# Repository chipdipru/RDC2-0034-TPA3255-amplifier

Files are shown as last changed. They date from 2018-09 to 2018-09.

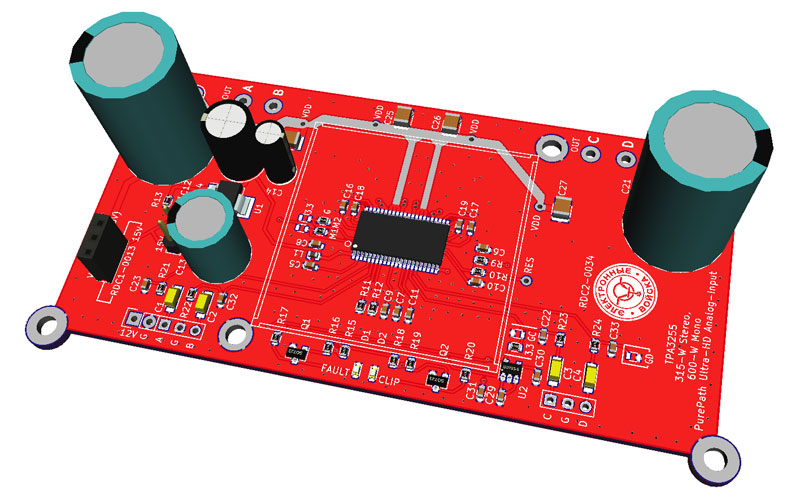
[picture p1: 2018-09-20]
RDC2-0034/pic/rdc2-0034.jpg

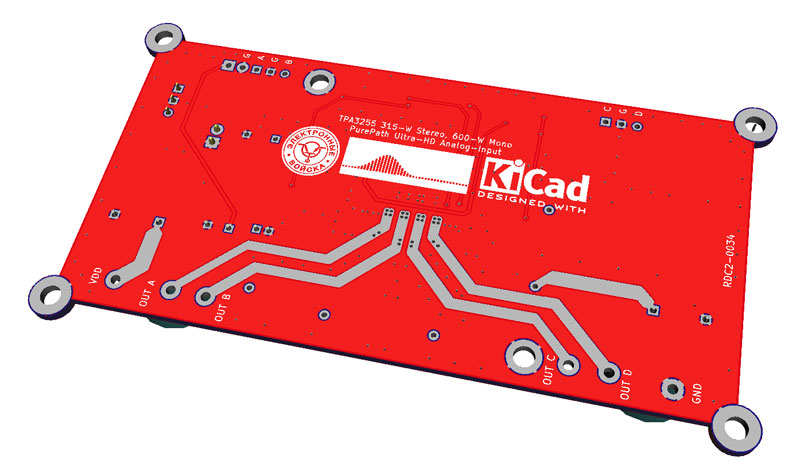
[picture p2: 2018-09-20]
RDC2-0034/pic/rdc2-0034_bot.jpg

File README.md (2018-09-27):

<p><a href="https://static.chipdip.ru/lib/893/DOC003893644.jpg" class="galery">RDC2-0034</a></p>

<p>Модуль RDC2-0034 представляет собой высокопроизводительный усилитель мощности класса D, который совмещает истинное качество звука премиум-класса с высоким КПД класса D.<br>Усилитель построен на микросхеме TPA3255. Это стереофонический аналоговый чип с цифровым усилителем Power Stage, предназначенный для работы с 4-омными громкоговорителями мощностью до 300 Вт на канал. Он имеет усовершенствованную интегрированную конструкцию обратной связи и исправление ошибок драйвера высокоскоростного шлюза (PurePath ™ Ultra-HD). Эта технология обеспечивает сверхнизкие искажения в звуковом диапазоне и превосходное качество звука.<br>RDC2-0034 сконфигурирован для работы с двумя каналами включенными по мостовой схеме (BTL).<br/>
 На аналоговый вход усилителя можно подавать как несимметричный так и симметричный (дифференциальный) сигнал.<br/>
 При необходимости два мостовых канала BTL можно включить параллельно, объединив их в один канал PBTL. При этом выходная мощность усилителя достигнет 600Вт.<br>Для обеспечения высококачественного высокоэффективного усиления звука требуется простой пассивный фильтр демодуляции цифрового сигнала. Модуль LCF.<br>Для питания схем управления и обработки сигнала усилителю требуется дополнительные источники питания – 12В и 3,3В. Модуль RDC1-0013 сформирует 15В из напряжения питания выходного каскада, а параметрические преобразователи на главной плате отдадут требуемые 12В и 3,3В.</p>
<h2>Технические характеристики</h2>
<p>Напряжение питания выходного каскада: 18-50 В<br>Количество каналов: 2 x BTL, 1 x PBTL<br>Сопротивление нагрузки: BTL 4-8 Ом<br>Сопротивление нагрузки: PBTL 2-3 Ом<br>Выходная мощность: BTL 318 Вт / 4 Ом 10% THD или 180 Вт / 8 Ом / 10% THD<br>Выходная мощность PBTL 607 Вт / 2 Ом / 10% THD<br>Выходная мощность: BTL 260 Вт / 4 Ом 1% THD или 150 Вт / 8 Ом / 1% THD<br>Выходная мощность: PBTL 480 Вт / 2 Ом / 1% THD<br>Коэффициент нелинейных искажений:0.006%<br>КПД с нагрузкой 4Ом: 90%</p>
<p>Схема основной платы усилителя.</p>
<p><a href="https://static.chipdip.ru/kits/9000491544/RDC2-0034_sch.png" class="galery">Схема</a></p>
<p>Подробную инструкцию по включению и конфигурации усилителя можно найти в разделе «Документы».</p>
<p>Это открытый проект! Лицензия, под которой он распространяется – <a href="https://creativecommons.org/licenses/by-sa/3.0/" class="link">Creative Commons - Attribution - Share Alike license</a>.</p>

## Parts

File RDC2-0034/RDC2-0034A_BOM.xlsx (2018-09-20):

RDC2-0034A
quantity | position | description | Manufacture
1 | IC1 | TPA3255DDV
1 | U1 | LM317AEMP SOT-223
1 | U2 | LP2985-33DBVR SOT-23-5
2 | Q1, Q2 | 2N7002
2 | D1, D2 | 0603 RED LED
4 | R1-R4 | DNP
2 | R5,R7 | DNP
2 | R6,R8 | R0 0603
1 | R9, R15, R18 | 47k, 0603 1%
3 | R10, R16, R19 | 100R, 0603 1%
1 | R11 | 22k, 0603 1%
1 | R12 | 30k, 0603 1%
1 | R13 | 4.7k, 0603 1%
1 | R14 | 560R, 0603 1%
2 | R17, R20 | 1k, 0603 1%
4 | C1-C4 | TECAP 10/10V A
4 | C5, C8, C10, C12 | 0.1u 0603
5 | C6, C22, C23, C32, C33 | 100p 0603
2 | C7, C9 | 1uF 0603
1 | C11 | 0,047 uF 0603 10%
4 | C16, C17, C18, C19 | 0,033 uF 0603 10% 50V
5 | C24, C25, C26, C27, C28 | 2,2 uF 1210 10% 100V
1 | C29 | 1 uF 0603 10%
1 | C30 | 0,01 uF 0603 10%
1 | C31 | 4,7 uF 0603 10%
1 | L1 | Inductor 10 μH, 0.08 A
2 | C20, C21 | 1000uF 63V D16 L25 P7.5
1 | C13 | 470uF 25V D10 L13 P5
1 | C14 | 10uF 35V D5 L11 P2
1 | C15 | 100uF 25 D8 L11.5 P3.5
1 | P3 | PBS-3
1 |  | PCB RDC2-0034

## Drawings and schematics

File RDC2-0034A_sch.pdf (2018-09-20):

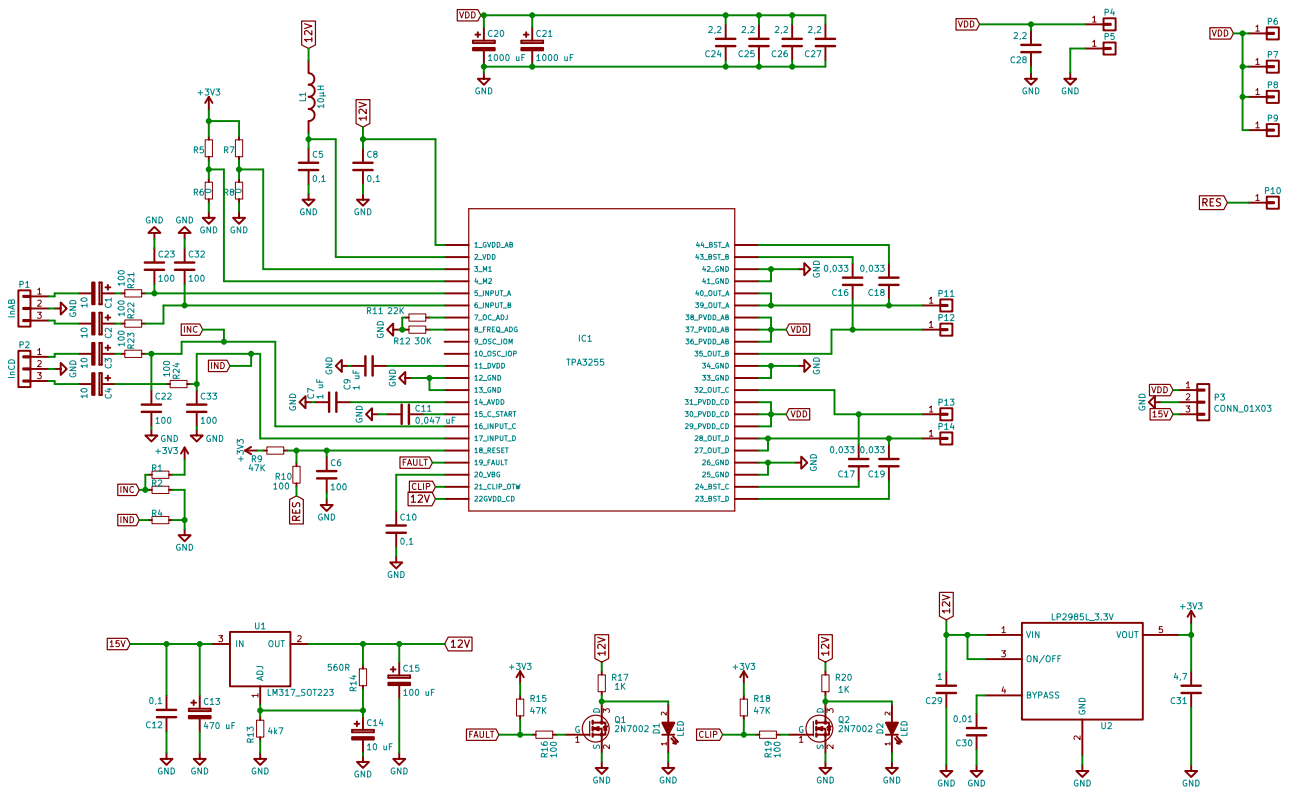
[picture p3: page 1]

2 ON/OFF 3 BYPASS 4 VOUT 5 U2

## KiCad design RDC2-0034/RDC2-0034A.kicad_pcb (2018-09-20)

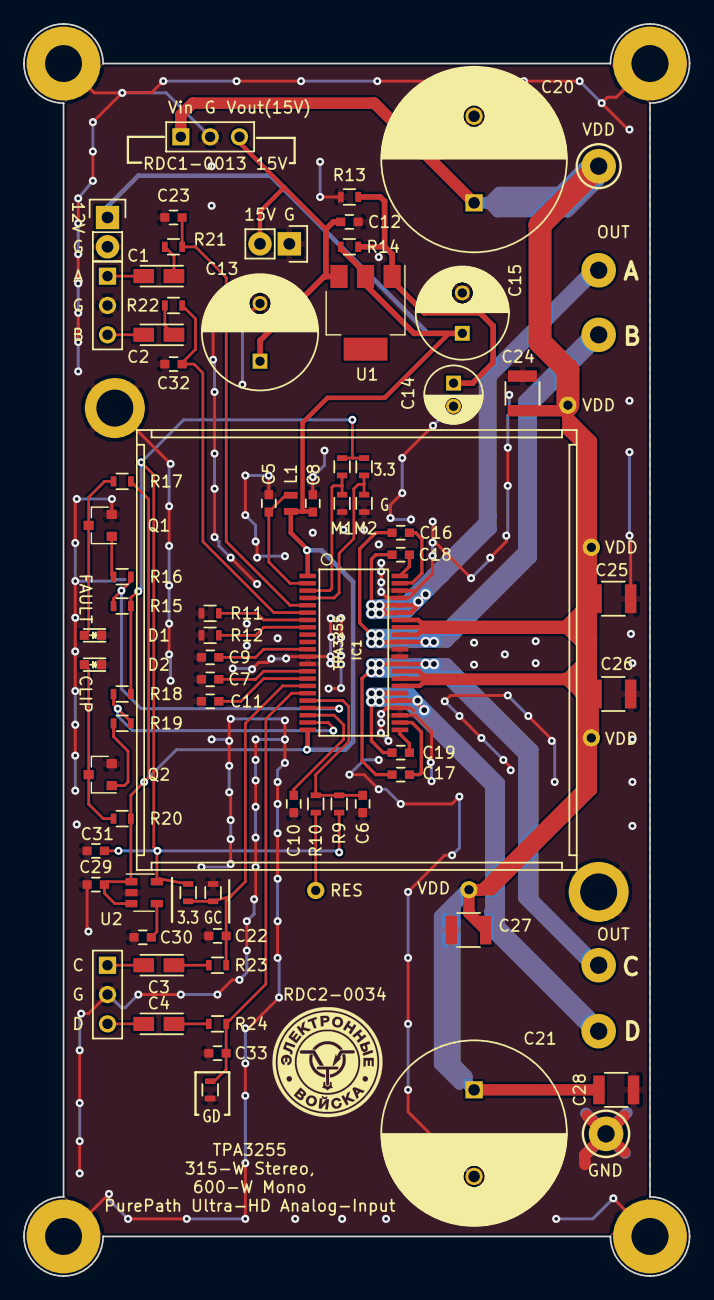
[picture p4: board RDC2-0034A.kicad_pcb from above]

Board: 2 copper layers, 57.7 x 108.5 mm, 78 parts (0 on the bottom side), 44 nets.

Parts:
C1, C2, C3, C4: 10; TantalC_SizeA_EIA-3216_Reflow
C5, C10, C12: 0,1; C_0603
C6, C22, C23, C32, C33: 100; C_0603
C7, C9: 1 uF; C_0603
C8: C; C_0603
C11: 0,047 uF; C_0603
C13: 470 uF; C_Radial_D10_L13_P5
C14: 10 uF; C_Radial_D5_L11_P2
C15: 100 uF; C_Radial_D8_L11.5_P3.5
C16, C17, C18, C19: 0,033; C_0603
C20, C21: 1000 uF; C_Radial_D16_L25_P7.5
C24, C25, C26, C27, C28: 2,2; C_1210
C29: 1; C_0603
C30: 0,01; C_0603
C31: 4,7; C_0603
D1, D2: LED; LED_0603
IC1: TPA3255; TSSOP-44
L1: 10μH; Neosid_Inductor_SM0603CG
P1: InAB; Pin_Header_Straight_1x03_mm
P2: InCD; Pin_Header_Straight_1x03_mm
P3: CONN_01X03; Pin_Header_Straight_1x03_mm
P4, P5, P11, P12, P13, P14: CONN_01X01; Measurement_Point_Round-TH_Big
P6, P7, P8, P9, P10: CONN_01X01; Measurement_Point_Round-TH_Small
Q1, Q2: 2N7002; SOT-23
R1, R2, R4, R5, R6, R7, R8: R; R_0603
R9: 10K; R_0603
R10, R16, R19, R21, R22, R23, R24: 100; R_0603
R11: 22K; R_0603
R12: 30K; R_0603
R13: 4k7; R_0603
R14: 560R; R_0603
R15, R18: 47K; R_0603
R17, R20: 1K; R_0603
U1: LM317_SOT223; SOT-223
U2: LP2985L_3.3V; SOT-23-5

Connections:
12V: C8.1, C15.1, C29.2, IC1.1, IC1.22, L1.1, R14.2, R17.1, R20.1, U1.2, U2.1, U2.3
15V: C12.2, C13.1, P3.3, U1.3
+3V3: C31.2, R1.2, R5.2, R7.2, R9.1, R15.1, R18.1, U2.5
CLIP: IC1.21, R18.2, R19.1
FAULT: IC1.19, R15.2, R16.1
GND: C5.2, C6.2, C7.2, C8.2, C9.2, C10.2, C11.2, C12.1, C13.2, C14.2, C15.2, C20.2, C21.2, C22.2, C23.1, C24.1, C25.1, C26.1, C27.1, C28.1, C29.1, C30.1, C31.1, C32.1, C33.2, D1.1, D2.1, IC1.12, IC1.13, IC1.25, IC1.26, IC1.33, IC1.34, IC1.41, IC1.42, P1.2, P2.2, P3.2, P5.1, Q1.2, Q2.2, R2.2, R4.2, R6.1, R8.1, R11.1, R12.1, R13.1, U2.2
INC: C22.1, IC1.16, R1.1, R2.1, R23.2
IND: C33.1, IC1.17, R4.1, R24.2
unnamed: C1.1, R21.1
unnamed: C1.2, P1.1
unnamed: C2.1, R22.1
unnamed: C2.2, P1.3
unnamed: C3.1, R23.1
unnamed: C3.2, P2.1
unnamed: C4.1, R24.1
unnamed: C4.2, P2.3
unnamed: C5.1, IC1.2, L1.2
unnamed: C6.1, IC1.18, R9.2, R10.2
unnamed: C7.1, IC1.14
unnamed: C9.1, IC1.11
unnamed: C10.1, IC1.20
unnamed: C11.1, IC1.15
unnamed: C14.1, R13.2, R14.1, U1.1
unnamed: C16.1, IC1.35, P12.1
unnamed: C16.2, IC1.43
unnamed: C17.1, IC1.24
unnamed: C17.2, IC1.32, P13.1
unnamed: C18.1, IC1.39, IC1.40, P11.1
unnamed: C18.2, IC1.44
unnamed: C19.1, IC1.23
unnamed: C19.2, IC1.27, IC1.28, P14.1
unnamed: C23.2, IC1.5, R21.2
unnamed: C30.2, U2.4
unnamed: C32.2, IC1.6, R22.2
unnamed: D1.2, Q1.3, R17.2
unnamed: D2.2, Q2.3, R20.2
unnamed: IC1.3, R7.1, R8.2
unnamed: IC1.4, R5.1, R6.2
unnamed: IC1.7, R11.2
unnamed: IC1.8, R12.2
unnamed: Q1.1, R16.2
unnamed: Q2.1, R19.2
RES: P10.1, R10.1
VDD: C20.1, C21.1, C24.2, C25.2, C26.2, C27.2, C28.2, IC1.29, IC1.30, IC1.31, IC1.36, IC1.37, IC1.38, P3.1, P4.1, P6.1, P7.1, P8.1, P9.1
